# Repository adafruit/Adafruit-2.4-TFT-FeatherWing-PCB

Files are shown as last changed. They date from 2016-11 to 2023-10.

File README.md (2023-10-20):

## Adafruit 2.4 TFT FeatherWing PCB

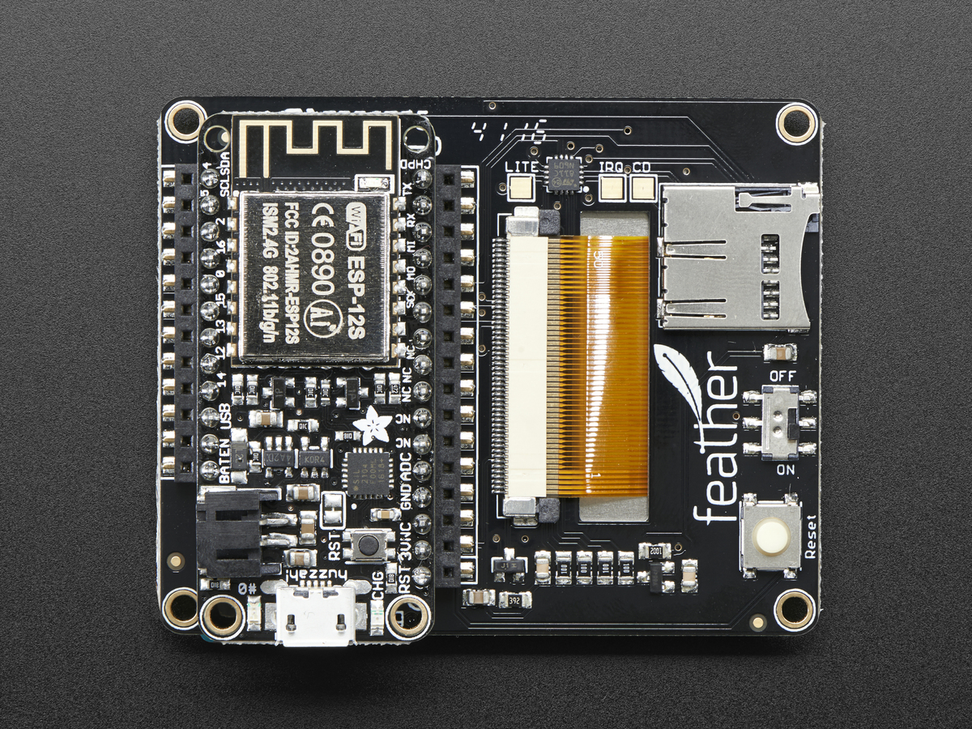
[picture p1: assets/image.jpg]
<a href="http://www.adafruit.com/products/3315"><br/>
Click here to purchase one from the Adafruit shop</a>

PCB files for the Adafruit 2.4" TFT FeatherWing. Format is EagleCAD schematic and board layout
* https://www.adafruit.com/products/3315

### Description

A Feather board without ambition is a Feather board without FeatherWings! Spice up your Feather project with a beautiful 2.4" touchscreen display shield with built in microSD card socket. This TFT display is 2.4" diagonal with a bright 4 white-LED backlight. You get  240x320 pixels with individual 16-bit color pixel control. It has way more resolution than a black and white 128x64 display. As a bonus, this display comes with a resistive touchscreen attached to it already, so you can detect finger presses anywhere on the screen.

This FeatherWing uses a SPI display so it works fast on each and every one of our Feathers. We also include an SPI resistive touchscreen controller so you only need one additional pin to add a high quality touchscreen controller. One more pin is used for an optional SD card that can be used for storing images for display.

This Wing comes fully assembled with dual sockets for your Feather to plug into. You get two sockets per pin so you can plug in wires if you want to connect to Feather pins. Alternatively, each pin has a large square pad on the PCB for direct soldering.

Four mounting holes make it easy to attach this Wing anywhere. We also include a big reset button and an on/off switch connected to the Feather Enable pin (note that the Teensy 3.x Feather does not use the Enable pin so the switch will not do anything with that type).

New! As of Oct 11, 2023 we've made a big redesign to this product: We now use the TSC2007 instead of the discontinued STMPE811 touchscreen controller. The screen and micro SD card are the same but any touchscreen code will need to be updated to use our Arduino or CircuitPython library. We've also updated the reset button to be right-angle and added a STEMMA QT port.

### License

Adafruit invests time and resources providing this open source design, please support Adafruit and open-source hardware by purchasing products from [Adafruit](https://www.adafruit.com)!

Designed by Limor Fried/Ladyada for Adafruit Industries.

Creative Commons Attribution/Share-Alike, all text above must be included in any redistribution. See license.txt for additional details.

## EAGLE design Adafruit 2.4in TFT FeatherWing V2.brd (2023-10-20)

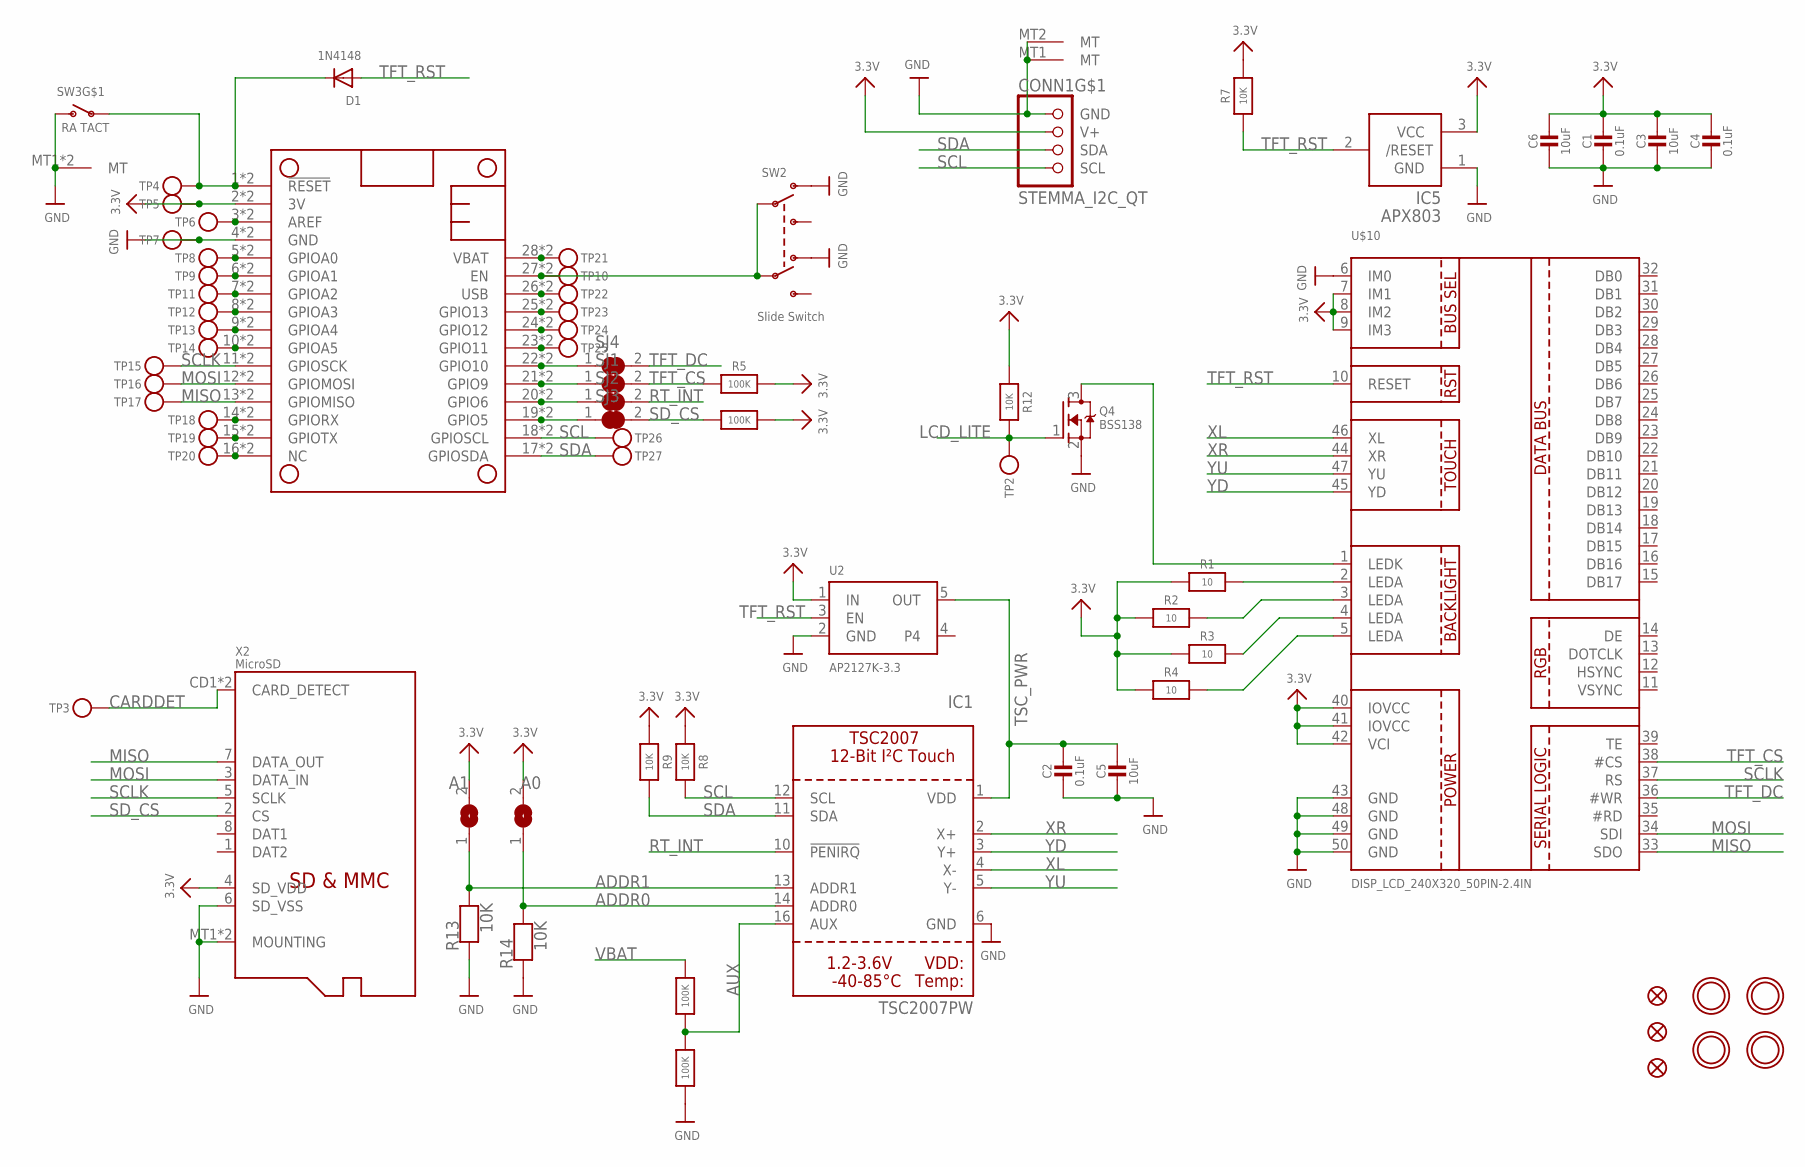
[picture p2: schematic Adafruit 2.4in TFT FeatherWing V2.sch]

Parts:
C1, C2, C4: 0.1uF; 0603-NO
C3, C5, C6: 10uF; 0805-NO
CONN1: STEMMA_I2C_QT; JST_SH4
D1: 1N4148; SOD-323
FID1, FID2, FID3: FIDUCIAL_1MM
IC1: TSC2007PW; TSSOP16
IC5: APX803; SOT23
ICSP_CLK1: A1; SOLDERJUMPER_ARROW_NOPASTE
ICSP_CLK2: A0; SOLDERJUMPER_ARROW_NOPASTE
MS2: FEATHERWING_SMTDUAL; FEATHERWING_SMT2
Q4: BSS138; SOT23-WIDE
R1, R2, R3, R4: 10; 0603-NO
R5, R6, R10, R11: 100K; 0603-NO
R7, R8, R9, R12, R13, R14: 10K; 0603-NO
SJ1, SJ2, SJ3, SJ4: SOLDERJUMPER_CLOSED; SOLDERJUMPER_CLOSEDWIRE
SW2: Slide Switch; EG1390
SW3: RA TACT; SPST_TACTILE_RA
TP2, TP3, TP4, TP5, TP6, TP7, TP8, TP9, TP10, TP11, TP12, TP13, TP14, TP15, TP16, TP17, TP18, TP19, TP20, TP21, TP22, TP23, TP24, TP25, TP26, TP27: TESTPOINTPAD2MM; TESTPOINT_PAD_2MM
U2: AP2127K-3.3; SOT23-5
U$9, U$11, U$15, U$17: MOUNTINGHOLE2.5; MOUNTINGHOLE_2.5_PLATED
U$10: DISP_LCD_240X320_50PIN-2.4IN; TFT_2.4IN_240X320_50PIN
X2: MicroSD; MICROSD

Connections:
3.3V: C1.1, C3.1, C4.1, C6.1, CONN1.2 (V+), IC5.3 (VCC), ICSP_CLK1.2, ICSP_CLK2.2, MS2.2 (3V), MS2.2' (3V), R1.1, R2.1, R3.1, R4.1, R5.2, R6.2, R7.2, R8.1, R9.1, R12.1, TP5.P$1, U2.1 (IN), U$10.7 (IM1), U$10.8 (IM2), U$10.9 (IM3), U$10.40 (IOVCC), U$10.41 (IOVCC), U$10.42 (VCI), X2.4 (SD_VDD)
!RESET: D1.C, MS2.1 (!RESET), MS2.1' (!RESET), SW3.1, TP4.P$1
A: MS2.5 (GPIOA0), MS2.5' (GPIOA0), TP8.P$1
ADDR0: IC1.14 (ADDR0), ICSP_CLK2.1, R14.2
ADDR1: IC1.13 (ADDR1), ICSP_CLK1.1, R13.2
AREF: MS2.3 (AREF), MS2.3' (AREF), TP6.P$1
AUX: IC1.16 (AUX), R10.1, R11.2
B: MS2.6 (GPIOA1), MS2.6' (GPIOA1), TP9.P$1
C: MS2.7 (GPIOA2), MS2.7' (GPIOA2), TP11.P$1
CARDDET: TP3.P$1, X2.CD1 (CARD_DETECT), X2.CD2 (CARD_DETECT)
D: MS2.8 (GPIOA3), MS2.8' (GPIOA3), TP12.P$1
E: MS2.9 (GPIOA4), MS2.9' (GPIOA4), TP13.P$1
EN: MS2.27 (EN), MS2.27' (EN), SW2.P1, SW2.P2, TP10.P$1
F: MS2.10 (GPIOA5), MS2.10' (GPIOA5), TP14.P$1
G: MS2.16 (NC), MS2.16' (NC), TP20.P$1
GND: C1.2, C2.2, C3.2, C4.2, C5.2, C6.2, CONN1.1 (GND), CONN1.MT1 (MT), CONN1.MT2 (MT), IC1.6 (GND), IC5.1 (GND), MS2.4 (GND), MS2.4' (GND), Q4.2 (S), R11.1, R13.1, R14.1, SW2.O1, SW2.O2, SW3.2 (S), SW3.MT1 (MT), SW3.MT2 (MT), TP7.P$1, U2.2 (GND), U$10.6 (IM0), U$10.43 (GND), U$10.48 (GND), U$10.49 (GND), U$10.50 (GND), X2.6 (SD_VSS), X2.MT1 (MOUNTING), X2.MT2 (MOUNTING)
H: MS2.19 (GPIO5), MS2.19' (GPIO5), SJ3.1
I: MS2.20 (GPIO6), MS2.20' (GPIO6), SJ2.1
J: MS2.21 (GPIO9), MS2.21' (GPIO9), SJ1.1
K: MS2.22 (GPIO10), MS2.22' (GPIO10), SJ4.1
L: MS2.23 (GPIO11), MS2.23' (GPIO11), TP25.P$1
LCD_LITE: Q4.1 (G), R12.2, TP2.P$1
M: MS2.24 (GPIO12), MS2.24' (GPIO12), TP24.P$1
MISO: MS2.13 (GPIOMISO), MS2.13' (GPIOMISO), TP17.P$1, U$10.33 (SDO), X2.7 (DATA_OUT)
MOSI: MS2.12 (GPIOMOSI), MS2.12' (GPIOMOSI), TP16.P$1, U$10.34 (SDI), X2.3 (DATA_IN)
N: MS2.25 (GPIO13), MS2.25' (GPIO13), TP23.P$1
unnamed: R4.2, U$10.5 (LEDA)
unnamed: R1.2, U$10.2 (LEDA)
unnamed: R2.2, U$10.3 (LEDA)
unnamed: R3.2, U$10.4 (LEDA)
unnamed: Q4.3 (D), U$10.1 (LEDK)
RT_INT: IC1.10 (!PENIRQ), SJ2.2
RX: MS2.14 (GPIORX), MS2.14' (GPIORX), TP18.P$1
SCL: CONN1.4 (SCL), IC1.12 (SCL), MS2.18 (GPIOSCL), MS2.18' (GPIOSCL), R8.2, TP26.P$1
SCLK: MS2.11 (GPIOSCK), MS2.11' (GPIOSCK), TP15.P$1, U$10.37 (RS), X2.5 (SCLK)
SDA: CONN1.3 (SDA), IC1.11 (SDA), MS2.17 (GPIOSDA), MS2.17' (GPIOSDA), R9.2, TP27.P$1
SD_CS: R6.1, SJ3.2, X2.2 (CS)
TFT_CS: R5.1, SJ1.2, U$10.38 (#CS)
TFT_DC: SJ4.2, U$10.36 (#WR)
TFT_RST: D1.A, IC5.2 (/RESET), R7.1, U2.3 (EN), U$10.10 (RESET)
TSC_PWR: C2.1, C5.1, IC1.1 (VDD), U2.5 (OUT)
TX: MS2.15 (GPIOTX), MS2.15' (GPIOTX), TP19.P$1
USB: MS2.26 (USB), MS2.26' (USB), TP22.P$1
VBAT: MS2.28 (VBAT), MS2.28' (VBAT), R10.2, TP21.P$1
XL: IC1.4 (X-), U$10.46 (XL)
XR: IC1.2 (X+), U$10.44 (XR)
YD: IC1.3 (Y+), U$10.45 (YD)
YU: IC1.5 (Y-), U$10.47 (YU)

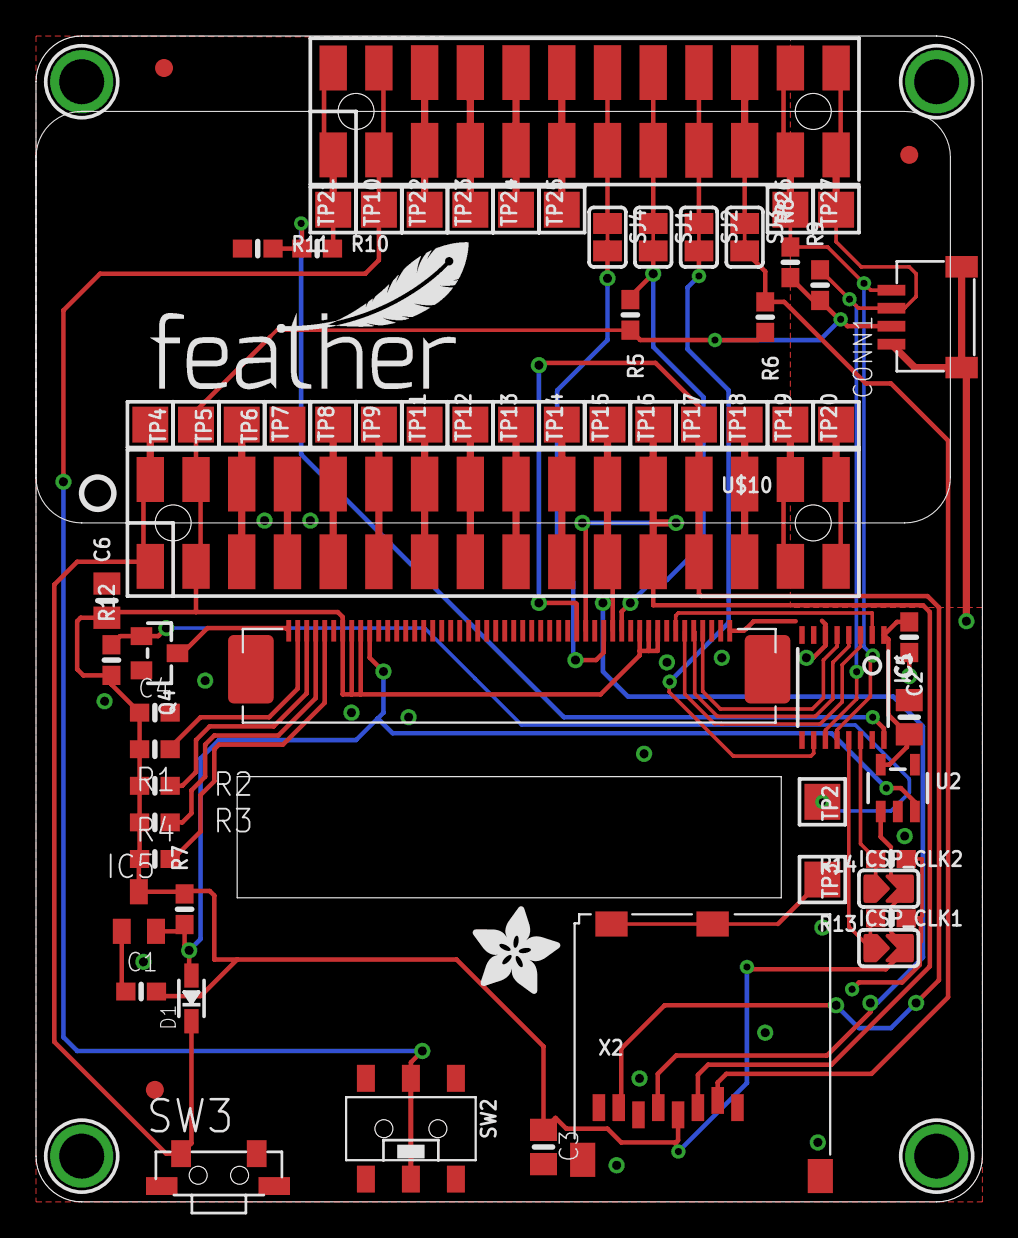
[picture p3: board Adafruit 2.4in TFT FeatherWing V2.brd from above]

Board: 2 copper layers, 52.6 x 64.8 mm, 87 parts (1 on the bottom side), 48 nets.

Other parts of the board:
PLABEL0: PLABEL0
PLABEL1: PLABEL1
PLABEL2: PLABEL2
PLABEL3: PLABEL3
PLABEL4: PLABEL4
PLABEL5: PLABEL5
PLABEL6: PLABEL6
PLABEL7: PLABEL7
PLABEL8: PLABEL8
PLABEL9: PLABEL9
PLABEL10: PLABEL10
PLABEL11: PLABEL11
PLABEL12: PLABEL12
PLABEL13: PLABEL13
U$29: FEATHERLOGO_MED
U$30: ADAFRUIT_5MM
U$34: PCBFEAT-REV-040
